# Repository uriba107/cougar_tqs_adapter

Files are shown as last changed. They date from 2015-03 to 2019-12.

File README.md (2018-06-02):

## TM cougar TQS USB adapter
This is a DIY USB adapter to make your TM Cougar throttle work as a standalone USB device.

**This software is based on the LUFA framework and distributed under MIT license as it stated in the [LUFA license](http://www.fourwalledcubicle.com/files/LUFA/Doc/120730/html/_page__license_info.html), Original license is provided here un modified in the file "license.txt".**

**Hardware is also distributed under MIT license, as specified under the "LICENSE_HW.md" file in this repo.**

**It is highly recommended that you flash or update the device with TQS connected. Without the throttle connected, there are a lot of floating connections which may result in weird behavior.**

http://pits.108vfs.org

#### Other useful stuff
##### Hardware
My version is based on Atmel ATMEGA 32u4 chip.
I've been using a replica of Sparkfun's Arduino Pro-Micro, with other versions YMMV.
Schematics can be found in the "*hardware*" folder.
for more details on the build process:
http://pits.108vfs.org/uriba/standalone-cougar-tqs-part-i/

In addition, you can buy a complete product based on the base design from ViperCore a well know store in the Viper pit builder community.
http://www.vipercore.nl/index.php/webshop/view/productdetails/virtuemart_product_id/57/virtuemart_category_id/14

##### Software
Source code provided can compiled and opened using Atmel Studio 7.
for more details check out the relevent blog posts:
http://pits.108vfs.org/uriba/standalone-cougar-tqs-part-ii/
http://pits.108vfs.org/uriba/standalone-cougar-tqs-part-iii/

##### Installation
Connect the Arduino Pro-micro to the computer, Drivers may be needed.
press the reset button twice in rapid succession to force device into "bootloader" mode.
Your computer will now Identify a new device, please note this device's COM port.
from the AVRdude folder, run the "*upload_code.bat*" file. In the window opened, type the device's com port number (eg. if device is on COM12, type "12").
double press the reset button of the arduino to force it into bootloaded mode again, and hit Enter. The code will now be uploaded to device. once completed, the device should register as a new joystick.

##### User Interface
The TQS code allows the user some calibration options via the use of "config mode".

To enter "Config Mode" press and hold Uncage <u>and</u> Speedbreaks open for 2 seconds.

Once enabled Config Mode will remain enabled for 20 seconds or until you select an options.

Available options:

| Button | Action |
|:---:|:---:|
| UHF | Exit Config Mode immidiatly (and save) |
| VHF | center Microstick (and exit config mode) |
| IFF IN | Save Current position of roteries as center (Detent calibration)|
| IFF OUT | drop all current Min/Max values for microstick and throttle. <br> Then, while in config mode, update Min/Max Values (20 seconds or UHF is pushed) |

an addition special mode is available to boot TQS controller to bootloader to allow device firmware to be updated.
to enter boot loader press and hold the following buttons for 5 seconds: Uncage, Cursor Enable, Speedbreaks Open.
##### Debugging
In the "*TQS_debugging*" folder, you will find an Arduino sketch to help you debug the hardware.
it will sample the device in exactly the same way the actual code does, but outputs the data out via the Serial console.
compile using "Arduino Micro" in the Arduino IDE.

###### Fun Facts
resolution of the device:

| Axis | Resolution |
|:-----|:---:|
|Throttle|12bits|
|Microstick|8 bits|
|ANT|10bits|
|RNG|10bits|

The code in action:<br>
IMAGE ALT TEXT HERE (https://www.youtube.com/watch?v=_ej5wT5lJjc)

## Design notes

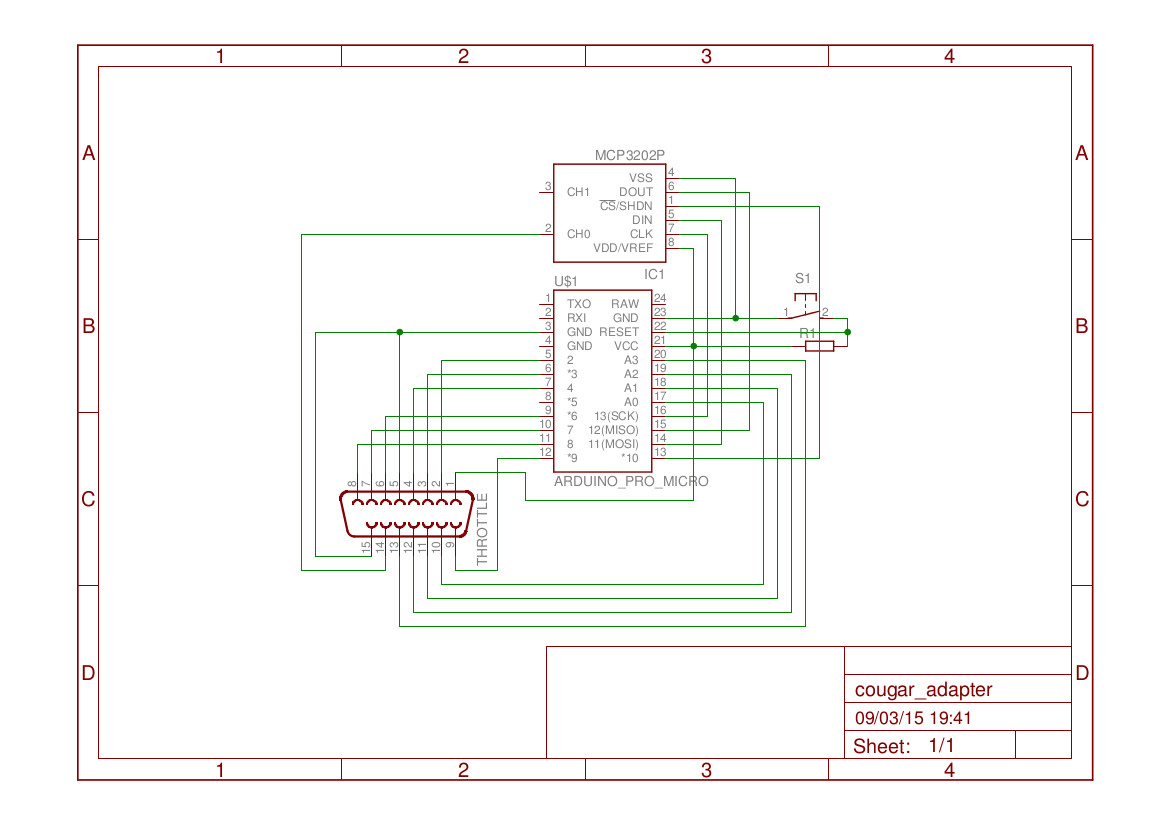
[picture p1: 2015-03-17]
hardware/cougar_adapter.jpg

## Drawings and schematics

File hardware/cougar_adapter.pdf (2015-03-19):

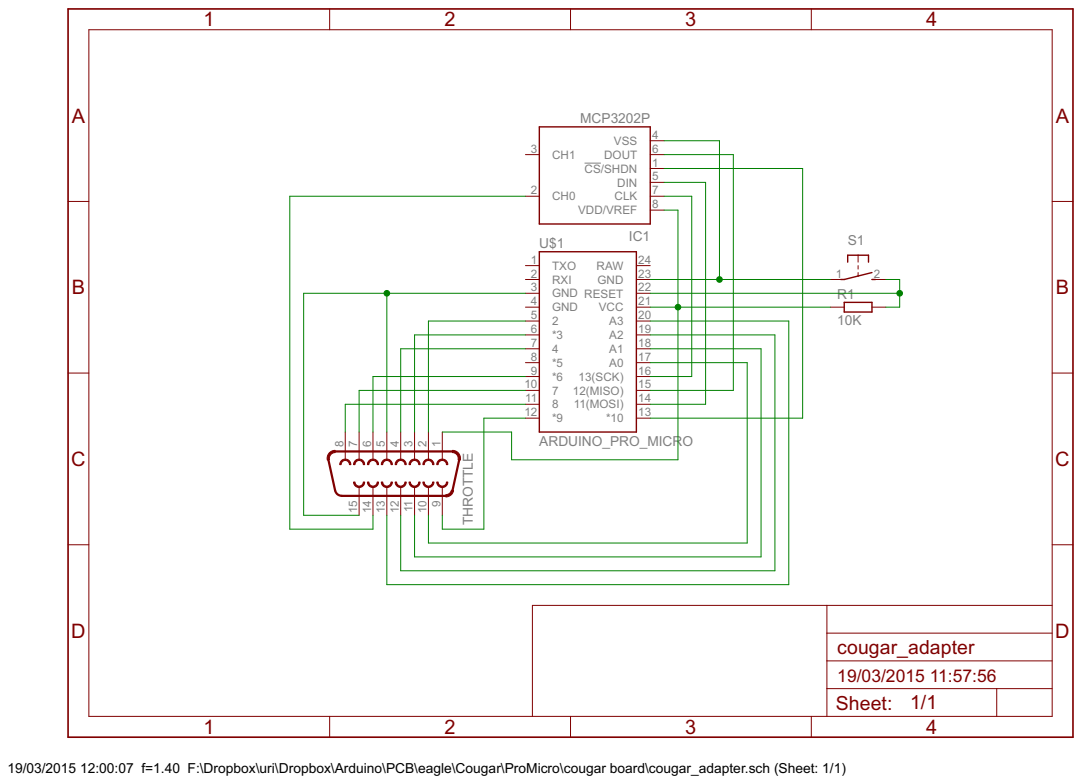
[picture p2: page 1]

8 9

19/03/2015 12:00:07 f=1.40 F:\Dropbox\uri\Dropbox\Arduino\PCB\eagle\Cougar\ProMicro\cougar board\cougar_adapter.sch (Sheet: 1/1)

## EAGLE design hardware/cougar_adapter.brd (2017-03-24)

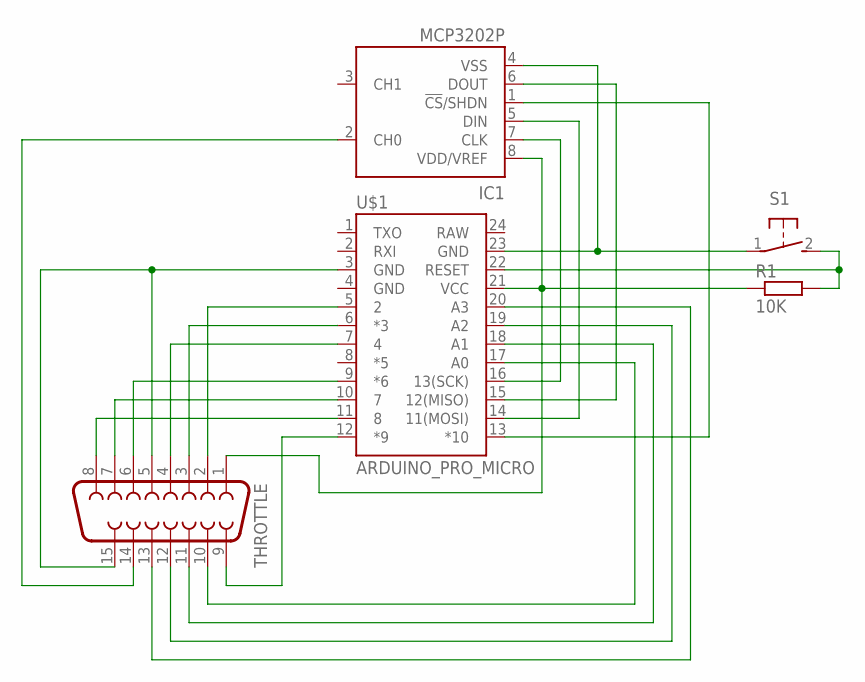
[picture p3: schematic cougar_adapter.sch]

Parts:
IC1: MCP3202P; DIL8
R1: 10K; 0204/7
S1: 31-XX; B3F-31XX
THROTTLE: F15HDH; HDF15H
U$1: ARDUINO_PRO_MICRO

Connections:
5V: IC1.8 (VDD/VREF), R1.1, THROTTLE.1, U$1.21 (VCC)
GND: IC1.4 (VSS), S1.1, THROTTLE.5, THROTTLE.15, U$1.3 (GND), U$1.23 (GND)
unnamed: IC1.5 (DIN), U$1.14 (11(MOSI))
unnamed: IC1.6 (DOUT), U$1.15 (12(MISO))
unnamed: IC1.7 (CLK), U$1.16 (13(SCK))
unnamed: R1.2, S1.2 (S), U$1.22 (RESET)
unnamed: THROTTLE.8, U$1.11 (8)
unnamed: THROTTLE.7, U$1.10 (7)
unnamed: THROTTLE.6, U$1.9 (*6)
unnamed: THROTTLE.4, U$1.7 (4)
unnamed: THROTTLE.3, U$1.6 (*3)
unnamed: IC1.2 (CH0), THROTTLE.14
unnamed: THROTTLE.9, U$1.12 (*9)
unnamed: THROTTLE.2, U$1.5 (2)
unnamed: THROTTLE.10, U$1.17 (A0)
unnamed: THROTTLE.11, U$1.18 (A1)
unnamed: THROTTLE.12, U$1.19 (A2)
unnamed: THROTTLE.13, U$1.20 (A3)
unnamed: IC1.1 (!CS!/SHDN), U$1.13 (*10)

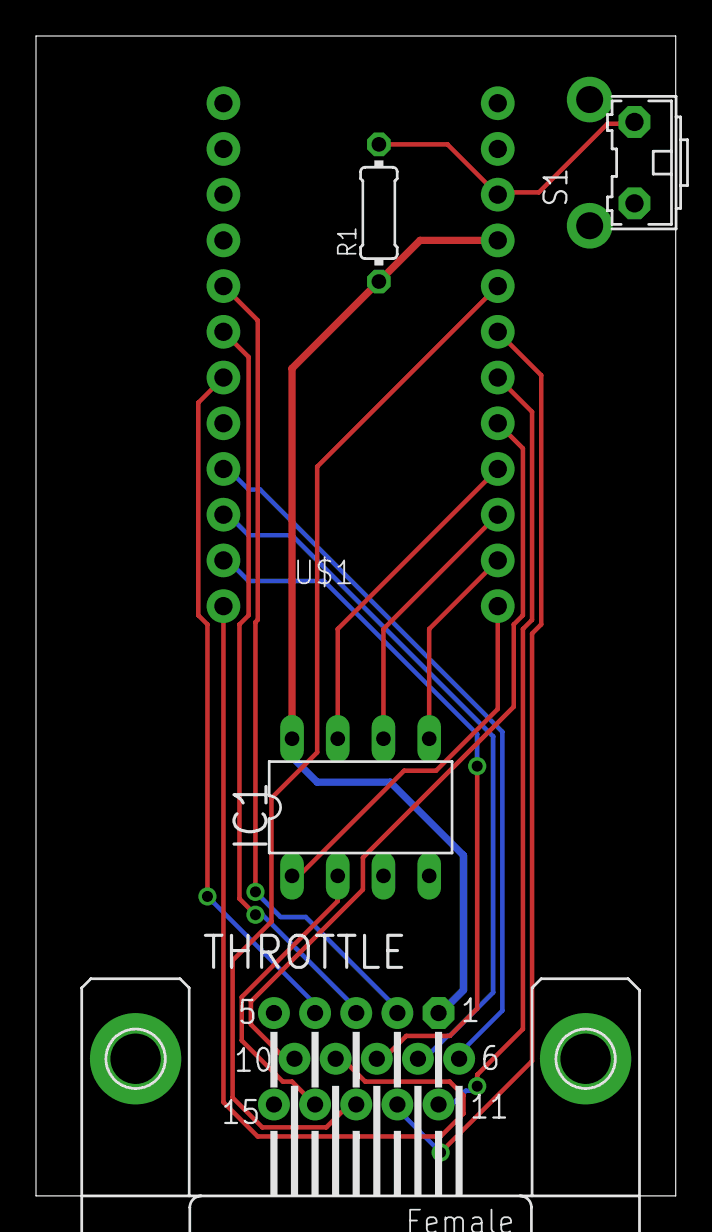
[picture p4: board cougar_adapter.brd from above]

Board: 2 copper layers, 35.5 x 64.4 mm, 5 parts (0 on the bottom side), 19 nets.

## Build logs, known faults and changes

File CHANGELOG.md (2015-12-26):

### Changelog
###### 0.0.3
  * Microstick - allow output scaling on a curve (rather then linear)
  * corrected switch polling method
  * Migrated to ATMEL studio 7

###### 0.0.2
  * Added Built-in deadzone to the Microstick. 
  * Now it's possible to press Cursor enable without slew.

###### 0.0.1
  * Initial Release

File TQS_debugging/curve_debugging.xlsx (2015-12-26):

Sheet: Sheet1
 | relativePos | curveFactor | computedVal | mapped |  | min | 0
250 | -0.5454545455 | -1.190082645 | -104.5454545 | 0 | 1 | max | 255
275 | -0.5 | -1 | 0 | 0 | 1 | curve | 2
300 | -0.4545454545 | -0.826446281 | 95.45454545 | 0 | 1 | in_min | 250
325 | -0.4090909091 | -0.6694214876 | 181.8181818 | 0 | 1 | in_max | 850
350 | -0.3636363636 | -0.5289256198 | 259.0909091 | 3.863636364 | 1 | mid | 550
375 | -0.3181818182 | -0.4049586777 | 327.2727273 | 32.84090909 | 1
400 | -0.2727272727 | -0.2975206612 | 386.3636364 | 57.95454545 | 1
425 | -0.2272727273 | -0.2066115702 | 436.3636364 | 79.20454545 | 1
450 | -0.1818181818 | -0.132231405 | 477.2727273 | 96.59090909 | 1
475 | -0.1363636364 | -0.07438016529 | 509.0909091 | 110.1136364 | 1
500 | -0.09090909091 | -0.03305785124 | 531.8181818 | 119.7727273 | 1
525 | -0.04545454545 | -0.00826446281 | 545.4545455 | 125.5681818 | 1
550 | 0 | 0 | 550 | 127.5 | 0
575 | 0.04545454545 | 0.00826446281 | 554.5454545 | 129.4318182 | 1
600 | 0.09090909091 | 0.03305785124 | 568.1818182 | 135.2272727 | 1
625 | 0.1363636364 | 0.07438016529 | 590.9090909 | 144.8863636 | 1
650 | 0.1818181818 | 0.132231405 | 622.7272727 | 158.4090909 | 1
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

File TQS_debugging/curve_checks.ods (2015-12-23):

ratio |  | curvefactor | computedVal | output value | input | 220
-0.6 | 1.944 | -1.944 | -519.2 | -326.91 | curve | 3
-0.5 | 1.125 | -1.125 | -68.75 | -135.46875 | midrange | 550
-0.4 | 0.576 | -0.576 | 233.2 | -7.14 | in_min | 250
-0.3 | 0.243 | -0.243 | 416.35 | 70.69875 | in_max | 850
-0.2 | 0.072 | -0.072 | 510.4 | 110.67 | out_min | 0
-0.1 | 0.009 | -0.009 | 545.05 | 125.39625 | out_max | 255
0 | 0 | 0 | 550 | 127.5
0.1 | 0.009 | 0.009 | 554.95 | 129.60375
0.2 | 0.072 | 0.072 | 589.6 | 144.33
0.3 | 0.243 | 0.243 | 683.65 | 184.30125
0.4 | 0.576 | 0.576 | 866.8 | 262.14
0.5 | 1.125 | 1.125 | 1168.75 | 390.46875
0.6 | 1.944 | 1.944 | 1619.2 | 581.91

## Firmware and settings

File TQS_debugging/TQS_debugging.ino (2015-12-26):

#include <SPI.h>

#define DEADZONE 15

#define AXIS_X 3
#define AXIS_Y 2
#define AXIS_ANT 0
#define AXIS_RNG 1

#define READ_X analogRead(AXIS_X)
#define READ_Y analogRead(AXIS_Y)
#define READ_ANT analogRead(AXIS_ANT)
#define READ_RNG analogRead(AXIS_RNG)
struct tqs {
  uint8_t  X; /**< Current absolute joystick X position, as a signed 8-bit integer */
  uint8_t  Y; /**< Current absolute joystick Y position, as a signed 8-bit integer */
  uint16_t  Z: 12; /**< Current absolute joystick Z position, as a signed 8-bit integer */
  uint16_t  ANT: 10; /**< Current absolute joystick Y position, as a signed 8-bit integer */
  uint16_t  RNG: 10; /**< Current absolute joystick Y position, as a signed 8-bit integer */
  uint16_t Buttons: 10;
};

struct Microstick {
  int16_t X;
  int16_t Y;
};

tqs throttle = {0};
Microstick microstick_zero = {0};

int32_t map_uri(int32_t InVal, int32_t in_min, int32_t in_max, int32_t out_min, int32_t out_max)
{
  // check limits to avoid out of bound results
  if (InVal <= in_min) {
    return out_min;
  } else if (InVal >= in_max) {
    return out_max;
  } else {
    // if input checks out, do the math
    return (InVal - in_min) * (out_max - out_min) / (in_max - in_min) + out_min;
  }
}
int32_t mapLargeNumbers(int32_t x, int32_t in_min, int32_t in_max, int32_t out_min, int32_t out_max)
{
#define FACTOR 10000
  if (x < in_min) {
    return out_min;
  } else if (x > in_max) {
    return out_max;
  } else {
    int ratio = ((((float)out_max - (float)out_min) / ((float)in_max - (float)in_min)) * FACTOR);
    return (((x - in_min) * (ratio)) / FACTOR) + out_min;
  }
}

int32_t mapCurve(int32_t inVal, int32_t in_min, int32_t in_max, int32_t out_min, int32_t out_max, int16_t axisZero, uint8_t sensetivity)
{
  /* Curve no 4 based on this source
  * https://github.com/achilleas-k/fs2open.github.com/blob/joystick_curves/joy_curve_notes/new_curves.md
  * 0 is most curved, 9 is linear, 10 will disable curve skip curve logic (linear output)
  */
  int32_t retVal;
  int16_t midRange = (in_min + in_max) / 2;
  if (abs(inVal - axisZero) < DEADZONE) {
    inVal = axisZero;

  }
  Serial.print("mapCurve: ");
  Serial.print(inVal);
  Serial.print("|");
  Serial.print(axisZero);
  if (sensetivity < 10) {
    // make a curve with sensetivity (WIP)
    float relativePos = (inVal - axisZero) / (float)axisZero;
    float curveFactor = pow(abs(relativePos), (3 - (sensetivity / 4.5)));
    if (relativePos < 0) {
      curveFactor *= -1;
    }
    Serial.print("|");
    Serial.print(relativePos);
    Serial.print("|");
    Serial.print((midRange * curveFactor) + midRange);
    retVal = map_uri(((midRange * curveFactor) + midRange), in_min, in_max, out_min, out_max);
  } else {
    // Skip the curve, and give linear output
    int16_t delta = midRange - axisZero;
    retVal =  map_uri(inVal + delta, in_min, in_max, out_min, out_max);
  }
  Serial.print("|");
  Serial.print(retVal);
  Serial.println("");
  return retVal;
}




void GetMicrostickZero() {
  //    uint32_t x = (analogRead(3)+analogRead(3)+analogRead(3))/3;
  //    uint32_t y = (analogRead(2)+analogRead(2)+analogRead(2))/3;
  //
  ////
  //  microstick_zero.X = map(x,250,850,-127,128);
  //  microstick_zero.Y = map(y,250,850,-127,128);

  //  microstick_zero.X = map((READ_X+READ_X+READ_X)/3,250,850,-127,128);
  //  microstick_zero.Y = map((READ_Y+READ_Y+READ_Y)/3,250,850,-127,128);
  microstick_zero.X = (uint32_t)(READ_X + READ_X + READ_X) / 3;
  microstick_zero.Y = (uint32_t)(READ_Y + READ_Y + READ_Y) / 3;

}

uint16_t pullMatrix(void) {
  uint16_t buttons = 0;
  //  byte debounce = 0xff;

  PORTD &= ~(1 << PD4); // pull "pin 4" down
  delay(1);
  // T6
  if ((PIND & _BV(7))) {
    buttons &= ~(1 << 6);
  } else {
    buttons |= (1 << 6);
  }
  // T1
  if (PINE & _BV(6)) {
    buttons &= ~(1 << 1);
  } else {
    buttons |= (1 << 1);
  }
  PORTD |= (1 << PD4); // bring "pin 4" back up

  // poll toggles	T2-5
  PORTD &= ~(1 << PD1); // pull "pin 3" down
  delay(1);
  //T2
  if ((PIND & _BV(7))) {
    buttons &= ~(1 << 2);
  } else {
    buttons |= (1 << 2);
  }
  // T3
  if (PINE & _BV(6)) {
    buttons &= ~(1 << 3);
  } else {
    buttons |= (1 << 3);
  }
  //T4
  if ((PINB & _BV(4))) {
    buttons &= ~(1 << 4);
  } else {
    buttons |= (1 << 4);
  }
  // T5
  if (PINB & _BV(5)) {
    buttons &= ~(1 << 5);
  } else {
    buttons |= (1 << 5);
  }
  PORTD |= (1 << PD1); // bring "pin 3" back up
  //Serial.println(buttons, BIN);
  // poll toggles	T7-10
  PORTD &= ~(1 << PD0); // pull "pin 3" down
  delay(1);

  //T7
  if ((PIND & _BV(7))) {
    buttons &= ~(1 << 7);
  } else {
    buttons |= (1 << 7);
  }
  // T8
  if (PINE & _BV(6)) {
    buttons &= ~(1 << 8);
  } else {
    buttons |= (1 << 8);
  }
  //T9
  if ((PINB & _BV(4))) {
    buttons &= ~(1 << 9);
  } else {
    buttons |= (1 << 9);
  }
  // T10
  if (PINB & _BV(5)) {
    buttons &= ~(1 << 10);
  } else {
    buttons |= (1 << 10);
  }
  PORTD |= (1 << PD0); // bring "pin 3" back up

  return (buttons >> 1);
}

uint16_t ReadADC(void) {
  uint16_t buff = 0;
  digitalWrite(10, LOW);
  SPI.transfer(0x01);
  buff = ((uint16_t)((SPI.transfer(0xa0) & ~(0xF0)) << 8)) | ((uint16_t)SPI.transfer(0));
  digitalWrite(10, HIGH);
  return buff;
}

uint16_t Readthrottle(void) {
  uint16_t buff = 0;
  digitalWrite(10, LOW);
  SPI.transfer(0x01);
  buff = ((uint16_t)((SPI.transfer(0xa0) & ~(0xF0)) << 8)) | ((uint16_t)SPI.transfer(0));
  digitalWrite(10, HIGH);
  return mapLargeNumbers(buff, 400, 3650, 0, 4095);
}

void setup() {
  // put your setup code here, to run once:
  pinMode(6, INPUT);
  pinMode(7, INPUT);
  pinMode(8, INPUT);
  pinMode(9, INPUT);

  pinMode(2, OUTPUT);
  digitalWrite(2, HIGH);
  pinMode(3, OUTPUT);
  digitalWrite(3, HIGH);
  pinMode(4, OUTPUT);
  digitalWrite(4, HIGH);

  pinMode(10, OUTPUT);
  digitalWrite(10, HIGH);
  SPI.begin();
  SPI.setClockDivider(SPI_CLOCK_DIV8);
  Serial.begin(9600);
  Serial.println("Start");

  GetMicrostickZero();
}

short col = 2;
uint16_t throttlemax = 0;
uint16_t throttlemin = 4096;
int xmin = 1023;
int xmax = 0;
int ymin = 1023;
int ymax = 0;
void loop() {
  // Get throttle - 0 for now

  throttle.Z = Readthrottle();
  if (throttle.Z > throttlemax) {
    throttlemax = throttle.Z;
  }
  if (throttle.Z < throttlemin) {
    throttlemin = throttle.Z;
  }

  // Get Axis data
  throttle.RNG = READ_RNG;
  throttle.ANT = READ_ANT;
//  int x = READ_X;
//  int y = READ_Y;
  //
  throttle.X = mapCurve(READ_X, 280, 830, 0, 255, microstick_zero.X, 5);
  throttle.Y = mapCurve(READ_Y, 280, 830, 0, 255, microstick_zero.Y, 5);
  //
//  if (x > xmax) {
//    xmax = x;
//  }
//  if (x < xmin) {
//    xmin = x;
//  }
//
//  if (y > ymax) {
//    ymax = y;
//  }
//  if (y < ymin) {
//    ymin = y;
//  }
  // Get buttons

  throttle.Buttons = pullMatrix();

  /// Print stuff
  //    Serial.print(" | Throttle: ");
  //    Serial.print(throttle.Z);
  ////    Serial.print(",Throttle max: ");
  ////    Serial.print(throttlemax);
  ////    Serial.print(",Throttle min: ");
  ////    Serial.print(throttlemin);
  //
  Serial.print(" | ministick: ");
  Serial.print(throttle.X);
  ////        Serial.print(x);
  Serial.print(',');
  Serial.print(throttle.Y);
  //    Serial.print(y);

  ////    Serial.print(",X max: ");
  ////    Serial.print(xmax);
  ////    Serial.print(",X min: ");
  ////    Serial.print(xmin);
  //  Serial.print(" | Microstick_zero: ");
  //  Serial.print(microstick_zero.X);
  //  Serial.print(",");
  //  Serial.print(microstick_zero.Y);
  ////////  //
  //    Serial.print(" | axis: ");
  //    Serial.print(throttle.RNG);
  //    Serial.print(',');
  //    Serial.print(throttle.ANT);
  //  //
  //    Serial.print(" | buttons: ");
  //    Serial.print(throttle.Buttons, BIN);


  Serial.println("");

  delay(200);


}

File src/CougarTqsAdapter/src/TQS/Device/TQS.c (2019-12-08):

/*
* tqs.c
*
* Created: 17/10/2016 03:43:35
*  Author: me
*/
#include "TQS.h"


// configure Global EEPROM pointers
uint8_t EEMEM NonVolatileOptions; // Unused stuff. left here not to mess up the address allocation for data retrivals.

uint16_t EEMEM NonVolatileThrottleMin =  THROTTLE_MIN;
uint16_t EEMEM NonVolatileThrottleMax = THROTTLE_MAX;
uint16_t EEMEM NonVolatileMicrostickXMin = MICROSTICK_MIN;
uint16_t EEMEM NonVolatileMicrostickXMax = MICROSTICK_MAX;
uint16_t EEMEM NonVolatileMicrostickYMin = MICROSTICK_MIN;
uint16_t EEMEM NonVolatileMicrostickYmax = MICROSTICK_MAX;
uint16_t EEMEM NonVolatileRngDetent = RNG_DETENT;
uint16_t EEMEM NonVolatileAntDetent = RNG_DETENT;


TqsLimits_t gTqsLimits;
Microstick_Report_Data_Raw_t gDetents;


bool gIsConfig = false;
bool gIsMinMaxing = false;
uint32_t gConfigTimer = 0;
uint32_t gRebootTimer = 0;
uint8_t gPowerLed = 255;


void TQS_Init(void) {
	SetupPins();
	SetupSPI();
	SetupADC();
	TimerInit();
	SetupLeds();

	ReadMicrostickZero();
	ReadMem();
}

void SetupADC(void)
{
	ADC_SetupChannel(X_CH); // A0 - ANT
	ADC_SetupChannel(Y_CH); // A1 - RNG
	ADC_SetupChannel(ANT_CH); // A2 - Y
	ADC_SetupChannel(RNG_CH); // A3 - X
	ADMUX |= ADC_RIGHT_ADJUSTED | ADC_REFERENCE_AVCC;
	ADC_Init(ADC_SINGLE_CONVERSION|ADC_PRESCALE_128);
}

void SetupSPI(void)
{
	DDRB |= (1<<DDB6); // set output
	PORTB |= (1<<PINB6); // pull high
	SPI_Init(SPI_SPEED_FCPU_DIV_4|SPI_MODE_MASTER);
}

void SetupPins(void)
{
	// Pins
	// Active pins 2(PD1),3(PD0),4(PD4)
	// Sensing Pins 6(PD7), 7(PE6), 8(PB4) ,9(PB5)
	// Set Active pins to Output
	DDRD |= (1<<DDD0) | (1<<DDD1) | (1<<DDD4);// set output
	PORTD |= (1<<PD0) | (1<<PD1) | (1<<PD4);// pull high

	// Make sure passive pins are input
	DDRD &= ~(1<<PIND7);
	DDRE &= ~(1<<PINE6);
	DDRB &= ~(1<<PINB4);
	DDRB &= ~(1<<PINB5);
}

void SetupLeds(void)
{
	// Set PC7 (Arduino Pin 13) For PWM
	// Set pin to output
	DDRC |= (1<<DDC7);

	// initiallize PWM4A
	// TCCR4A |= (1 << PWM4A)
	cbi(TCCR4A, COM4A0);

	// Now turn LED on for full cycle
	setStatusLed(gPowerLed);
}


void setStatusLed(uint8_t power){
	if (power == 0 ){
		cbi(TCCR4A, COM4A1);
		PORTC &= ~(1<<PORTC7);
		} else if (power == 255) {
		cbi(TCCR4A, COM4A1);
		PORTC |= (1<<PORTC7);
		} else {
		// set timers. pin is OC4A in PMW
		//		TCCR4A |= (1 << PWM4A) |(1 << COM4A1);
		//		TCCR4A &= ~(1 << COM4A0);
		sbi(TCCR4A, COM4A1);
		OCR4A = power;
	}

}

///////// EEPROM /////////////////////
void WriteMem(void){
	// This function will write to EEPROM any values that had been changed in runtime (to save EEPROM lifetime)

	//uint8_t volatile VolatileOptions;
	uint16_t volatile VolatileThrottleMin;
	uint16_t volatile VolatileThrottleMax;
	uint16_t volatile VolatileMicrostickXMin;
	uint16_t volatile VolatileMicrostickXMax;
	uint16_t volatile VolatileMicrostickYMin;
	uint16_t volatile VolatileMicrostickYmax;
	uint16_t volatile VolatileRngDetent;
	uint16_t volatile VolatileAntDetent;

	// Read EEPROM
	VolatileThrottleMin = eeprom_read_word(&NonVolatileThrottleMin);
	VolatileThrottleMax = eeprom_read_word(&NonVolatileThrottleMax);
	VolatileMicrostickXMin = eeprom_read_word(&NonVolatileMicrostickXMin);
	VolatileMicrostickXMax = eeprom_read_word(&NonVolatileMicrostickXMax);
	VolatileMicrostickYMin = eeprom_read_word(&NonVolatileMicrostickYMin);
	VolatileMicrostickYmax = eeprom_read_word(&NonVolatileMicrostickYmax);
	VolatileRngDetent = eeprom_read_word(&NonVolatileRngDetent);
	VolatileAntDetent = eeprom_read_word(&NonVolatileAntDetent);


	if (gTqsLimits.Z.Min != VolatileThrottleMin) {
		eeprom_update_word(&NonVolatileThrottleMin,gTqsLimits.Z.Min);
	}
	if (gTqsLimits.Z.Max != VolatileThrottleMax) {
		eeprom_update_word(&NonVolatileThrottleMax,gTqsLimits.Z.Max);
	}
	if (gTqsLimits.X.Min != VolatileMicrostickXMin) {
		eeprom_update_word(&NonVolatileMicrostickXMin,gTqsLimits.X.Min);
	}
	if (gTqsLimits.X.Max != VolatileMicrostickXMax) {
		eeprom_update_word(&NonVolatileMicrostickXMax,gTqsLimits.X.Max);
	}
	if (gTqsLimits.Y.Min != VolatileMicrostickYMin) {
		eeprom_update_word(&NonVolatileMicrostickYMin,gTqsLimits.Y.Min);
	}
	if (gTqsLimits.Y.Max != VolatileMicrostickYmax) {
		eeprom_update_word(&NonVolatileMicrostickYmax,gTqsLimits.Y.Max);
	}
	if (gDetents.Y != VolatileAntDetent) {
		eeprom_update_word(&NonVolatileAntDetent,gDetents.Y);
	}
	if (gDetents.X != VolatileRngDetent) {
		eeprom_update_word(&NonVolatileRngDetent,gDetents.X);
	}
}

void ReadMem(void){

	//uint8_t volatile VolatileOptions;
	uint16_t volatile VolatileThrottleMin;
	uint16_t volatile VolatileThrottleMax;
	uint16_t volatile VolatileMicrostickXMin;
	uint16_t volatile VolatileMicrostickXMax;
	uint16_t volatile VolatileMicrostickYMin;
	uint16_t volatile VolatileMicrostickYmax;
	uint16_t volatile VolatileRngDetent;
	uint16_t volatile VolatileAntDetent;


	// Read EEPROM
	//VolatileOptions = eeprom_read_byte(&NonVolatileOptions);
	VolatileThrottleMin = eeprom_read_word(&NonVolatileThrottleMin);
	VolatileThrottleMax = eeprom_read_word(&NonVolatileThrottleMax);
	VolatileMicrostickXMin = eeprom_read_word(&NonVolatileMicrostickXMin);
	VolatileMicrostickXMax = eeprom_read_word(&NonVolatileMicrostickXMax);
	VolatileMicrostickYMin = eeprom_read_word(&NonVolatileMicrostickYMin);
	VolatileMicrostickYmax = eeprom_read_word(&NonVolatileMicrostickYmax);
	VolatileRngDetent = eeprom_read_word(&NonVolatileRngDetent);
	VolatileAntDetent = eeprom_read_word(&NonVolatileAntDetent);

	// Check and place values
	//#define EEPROM_EMPTY_BYTE(b) (b == 0xFF)
	//#define EEPROM_EMPTY_WORD(w) (w == 0xFFFF)
#define EEPROM_EMPTY_BYTE(b) ((b) == (0) ? 1 : (b) == (0xFF) ? 1 : 0)
#define EEPROM_EMPTY_WORD(w) ((w) == (0) ? 1 : (w) == (0xFFFF) ? 1 : 0)
	// result = a > b ? x : y;

	//gOptions = EEPROM_EMPTY_BYTE(VolatileOptions) ? 0 : VolatileOptions;
	gTqsLimits.Z.Min = EEPROM_EMPTY_WORD(VolatileThrottleMin) ? THROTTLE_MIN : VolatileThrottleMin;
	gTqsLimits.Z.Max = EEPROM_EMPTY_WORD(VolatileThrottleMax) ? THROTTLE_MAX : VolatileThrottleMax;
	gTqsLimits.X.Min = EEPROM_EMPTY_WORD(VolatileMicrostickXMin) ? MICROSTICK_MIN : VolatileMicrostickXMin;
	gTqsLimits.X.Max = EEPROM_EMPTY_WORD(VolatileMicrostickXMax) ? MICROSTICK_MAX : VolatileMicrostickXMax;
	gTqsLimits.Y.Min = EEPROM_EMPTY_WORD(VolatileMicrostickYMin) ? MICROSTICK_MIN : VolatileMicrostickYMin;
	gTqsLimits.Y.Max = EEPROM_EMPTY_WORD(VolatileMicrostickYmax) ? MICROSTICK_MAX : VolatileMicrostickYmax;
	gDetents.Y = EEPROM_EMPTY_WORD(VolatileAntDetent) ? ANT_DETENT : VolatileAntDetent;
	gDetents.X = EEPROM_EMPTY_WORD(VolatileRngDetent) ? RNG_DETENT : VolatileRngDetent;
}

uint16_t readSPIADC(){
	PORTB &= ~(1<<PINB6); // Pull shift register CS low
	SPI_SendByte(0x01); //send start
	uint16_t result = ((uint16_t)(SPI_TransferByte(0xa0) & ~(0xF0)) << 8) | ((uint16_t)SPI_ReceiveByte());
	PORTB |= (1<<PINB6); // Pull Shift register CS high
	return result;
}
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

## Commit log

2015-03-17 Initial Commit - working Cougar TQS adapter
    [cougar_adapter.sch]
2015-03-17 Update and rename README.txt to README.md
    Switch to proper MD syntax
2015-03-19 Version 0.0.2: Better deadzone on the Microstick
    [cougar_adapter.sch]
2015-12-23 pre-0.0.3
    Migration to Atmel studio 7.0
    starting implementation of curve on the microstick
    [curve_checks.ods]
2015-12-25 pre-0.0.3 - curves are still in overflow
    [curve_debugging.xlsx]
2015-12-26 0.0.3 - microstick now has a response curve
    [curve_debugging.xlsx]
2017-03-24 updated board and schematics
    [cougar_adapter.brd]
2017-05-19 Disconnecting Throttle from board will no longer "push all the buttons"
    [TQS.c]
2018-01-05 Possible fix for EEPROM loading.
    Adjustments to Microstick and ANT Roteries sensitivities based on Driver feedback
    [TQS.c]
2019-09-28 0.0.9 change delay using ADC to allow very long cables to be used. fixed bug in ANT elevation logic.
    [TQS.c]
2019-09-30 fixed curve on ANT
    [TQS.c]
2019-10-04 added cutoff virtual button
2019-10-04 added cutoff virtual button Disabled ANT ELEV curve, it's foobar again.

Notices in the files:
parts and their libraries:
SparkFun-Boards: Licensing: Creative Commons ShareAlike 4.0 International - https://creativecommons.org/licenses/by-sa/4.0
